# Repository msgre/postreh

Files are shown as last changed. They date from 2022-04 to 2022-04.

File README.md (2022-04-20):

Postřehová hra pro 2-4 hráče, realizovaná pro [Vrtuli, svět her a
poznání](https://zlatesipy.tomici.cz/vrtule/).

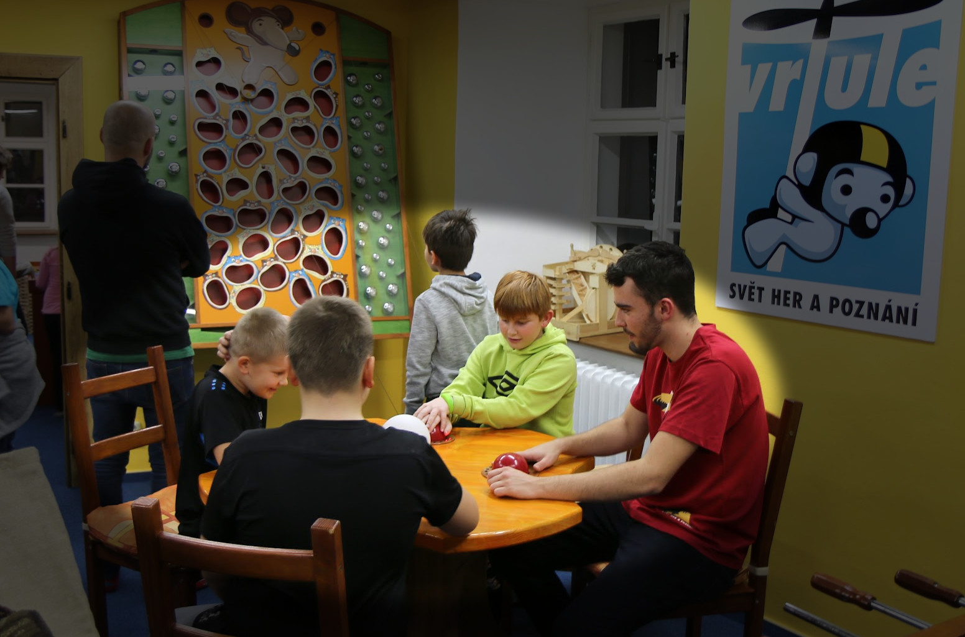
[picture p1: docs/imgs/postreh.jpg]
Hra Postřeh Hra postřeh


Jde o stolek se 4 tlačítky a světlem uprostřed.

Cílem hry je co nejdříve získat devět bodů. Ty se získávají stiskem tlačítka
ihned po rozsvícení světla uprostřed. Pokud se některý hráč unáhlí a stiskne
tlačítko ještě před rozsvícením, o bod přichází.

[Demonstrační video](https://youtu.be/h4fl8f8gwDo).

### Obsah

* [Hardware](#hardware)
* [Software](#software)
* [3D modely](#3d-modely)
* [Polepy](#polepy)
* [Opravy](#opravy)

## Hardware

Hru ovládá malý jednodeskový počítač Raspberry Pico (`U1`) a Micropython kód z
tohoto repozitáře. Hlavní světlo a signalizace získaných bodů jsou zrealizovány s
pomocí programovatelných diod Neopixel. Protože RPico používá 3.3V logiku, je
nutné mezi LED pásek a počítač vložit převodník logických úrovní (`U2`).
Tlačítka ze stolu (`SW1..4`) připínají 5V přímo na piny RPico. Na napájecích
pinech počítače a u konektorů vedoucích do Neopixelů jsou [dle
doporučení](https://learn.adafruit.com/adafruit-neopixel-uberguide/best-practices)
připojeny odrušovací kondenzátory (`C1..3`).

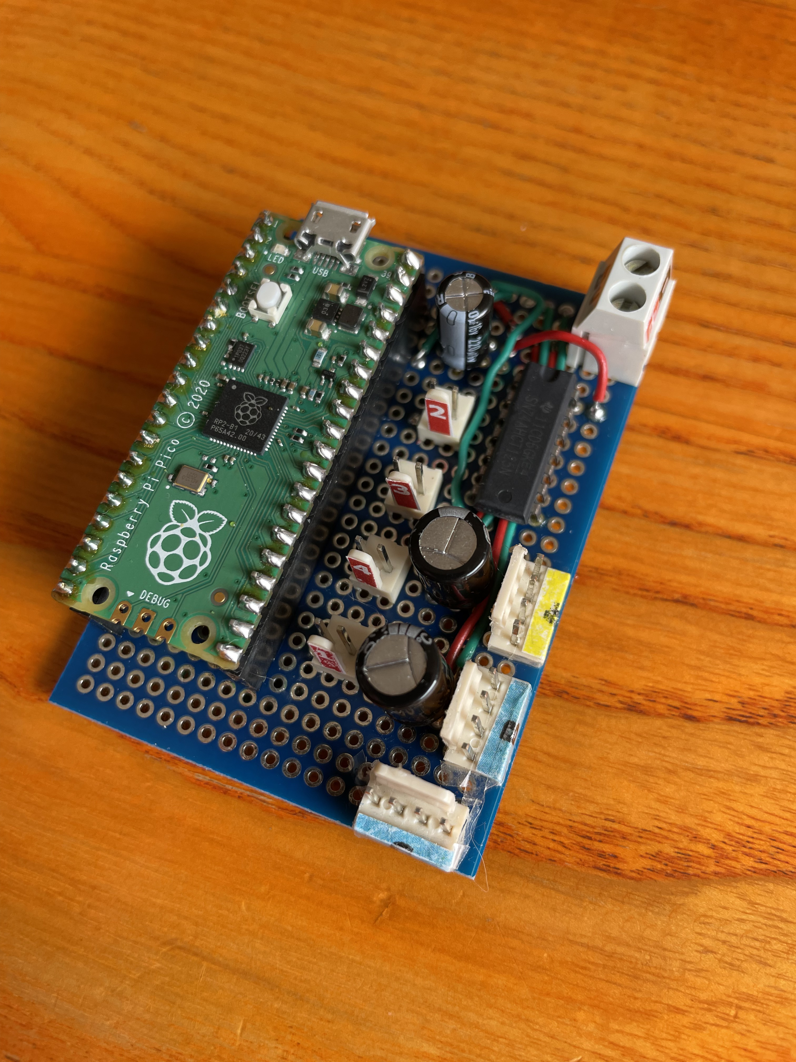
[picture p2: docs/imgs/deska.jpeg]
Ovládací deska


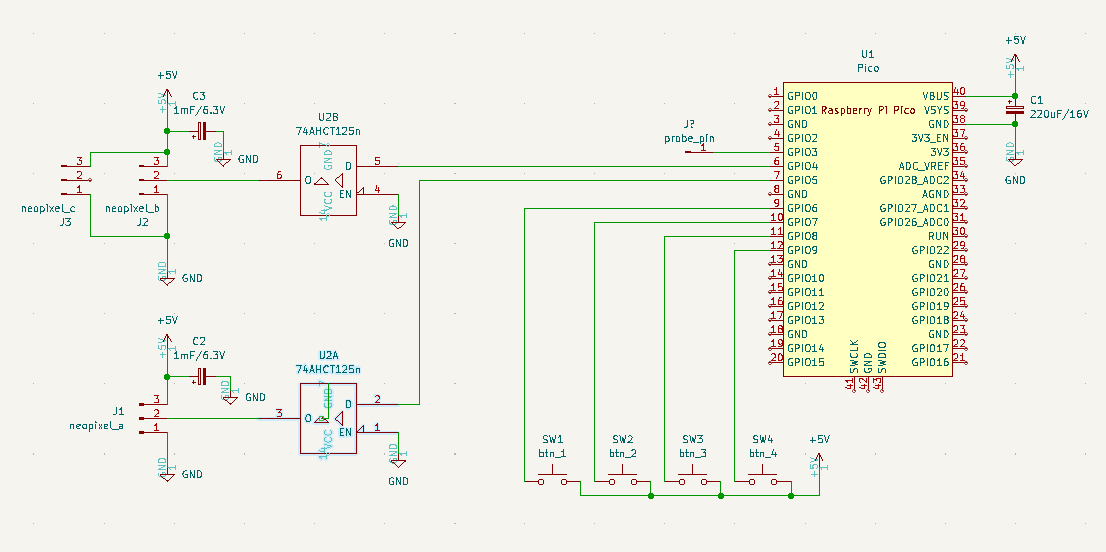
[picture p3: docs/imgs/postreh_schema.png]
Schéma zapojení


Do hlavního světla vedou 2 kablíky (`B` a `C`). Kabel `C` ale přivádí pouze
napájení doprostřed pásku, to aby diody v druhé polovině v důsledku úbytku
napětí nesvítily méně než ty v první polovině.

Upozornění: na datovém vstupu Neopixelů je připájen odpor 390R, který chrání
první diodu v pásku (ve schématu výše není zakreslen).

[Schéma zapojení v KiCadu](/schema/)

**Napájení**

Celou hru napájí malý spínaný 50W zdroj, připojený do svorek +/- na okraji desky.

Během vývoje jsem ale desku připojoval (a napájel) z externího docku co mám
u počítače, zkrz standardní RPico USB vstup. Pro klid duše je asi vhodné v této
konfiguraci stáhnout jas diod (konstanty `LED_MAIN_BRIGHTNESS` a `LED_NUMBERS_BRIGHTNESS`
v souboru `postreh/config.py`), ať proudy tekoucí z docku nejsou moc velké.

Hru utáhne i Powerbanka, opět připojená standardně přes RPico USB vstup
(odzkoušeno).

## Software

Hra je naprogramovaná pro Micropython v1.17 (Python 3.4).

Nahrávání SW dovnitř RPico je možné provést s pomocí aplikace
[Thonny](https://thonny.org/). Stačí nakopírovat soubor [`main.py`](/main.py) a kompletní
podadresář [`postreh/`](/postreh/).

Logika aplikace není nijak složitá. Snažil jsem se rozdělit funkční celky do
samostaných modulů. Hra se řídí stavovou mašinou dle následujícího nákresu:

Stavy

Jednotlivé stavy jsou popsány soubory v [`postreh/states/`](/postreh/states/).

V adresáři [`postreh/effects/`](postreh/effects/) jsou naimplementovaný vizuální efekty pro
Neopixel LEDky. Protože jejich tunění zabralo hodně času, jsou v
[`postreh/effects/tests/`](postreh/effects/tests/) jednoduché skripty, které po spuštěním v aplikaci
Thonny efekt oddemonstrují.

## 3D modely

V adresáři [`3d/`](/3d/) jsou uložené zdrojové 3D modely (Fusion 360) pro díly použité
v Postřehu a z nich vygenerované `.gcode` pro patřičné materiály a tiskárnu Prusa MK3.

[**Signalizace skóre**](/3d/postreh_cisla_u_tlacitek_v10.f3d)

Kulatý díl s prosvětlenými čísly. Skládá se z několika částí.

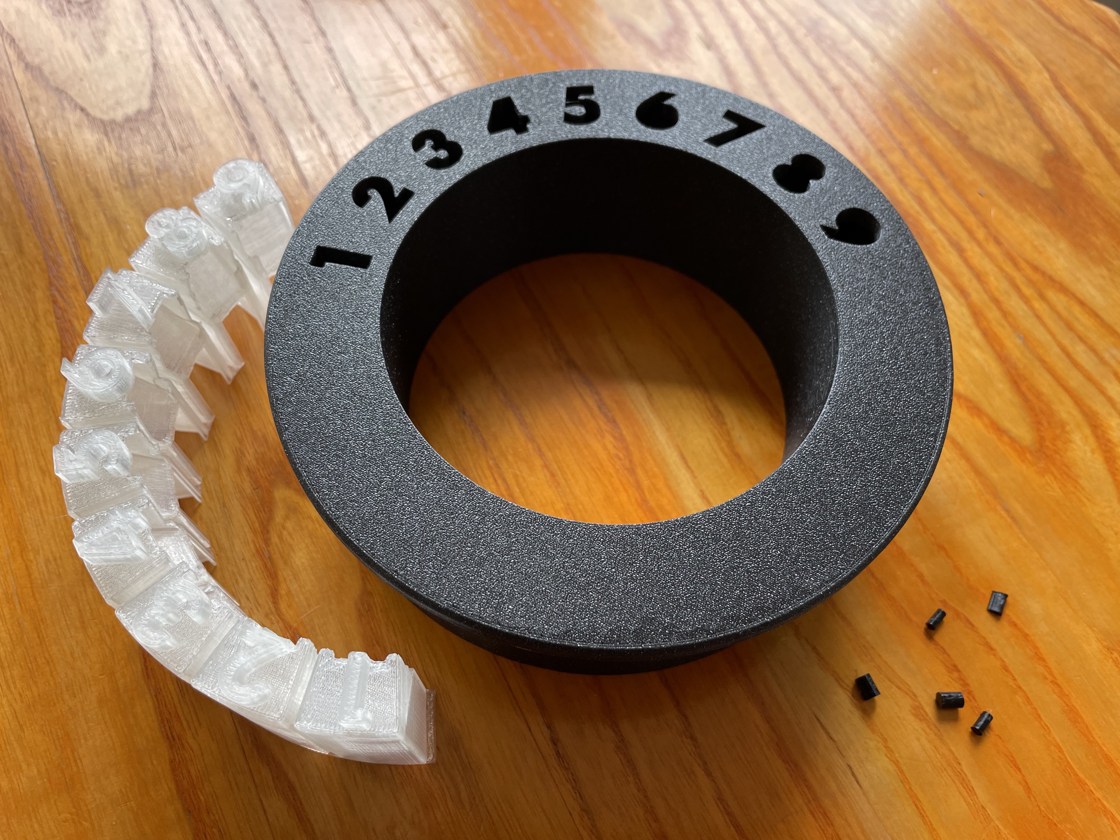
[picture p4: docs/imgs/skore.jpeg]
Signalizace skóre Signalizace skóre, starší verze


Hlavní díl (černý Prusament PETG) do kterého jsou vloženy Neopixely:

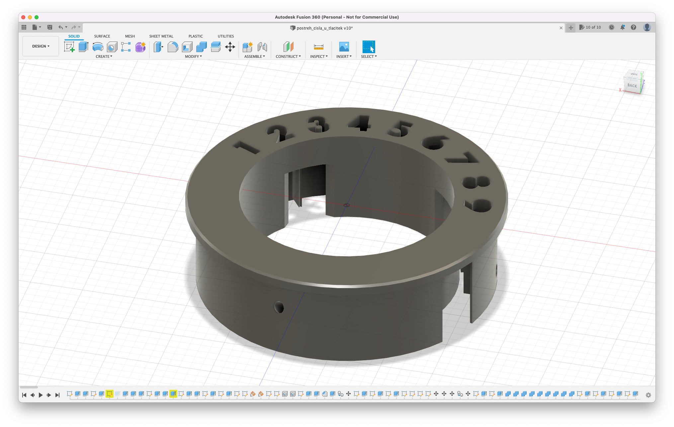
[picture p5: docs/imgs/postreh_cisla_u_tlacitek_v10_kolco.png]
Hlavní černý díl


Průsvitný díl s čísly (průsvitné noname PLA), který se vkládá do černého.
Jeho součástí jsou i šikmé plošky s nalepenou zrcadlovou fólií, která odráží
světlo z Neopixelů do čísel. Zároveň se stará o zafixování pozice Neopixel
pásku:

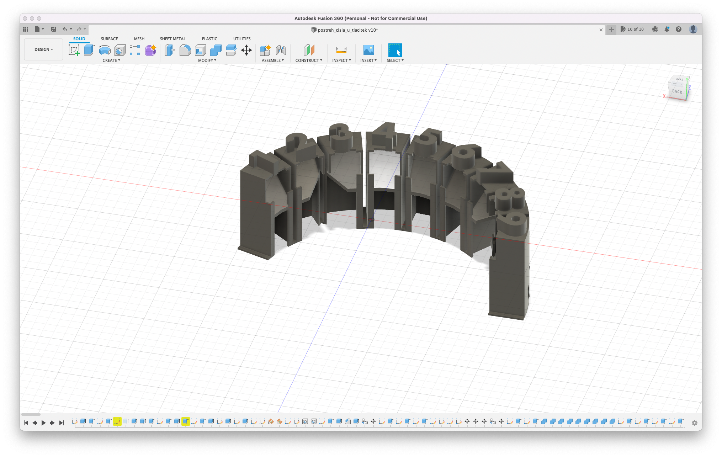
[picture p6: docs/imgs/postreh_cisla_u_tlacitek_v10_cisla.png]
Průsvitný díl s čísly


Titěrné středy čísel (černý Prusament PETG), které se vlepí dovnitř děr
v průhledném dílu:

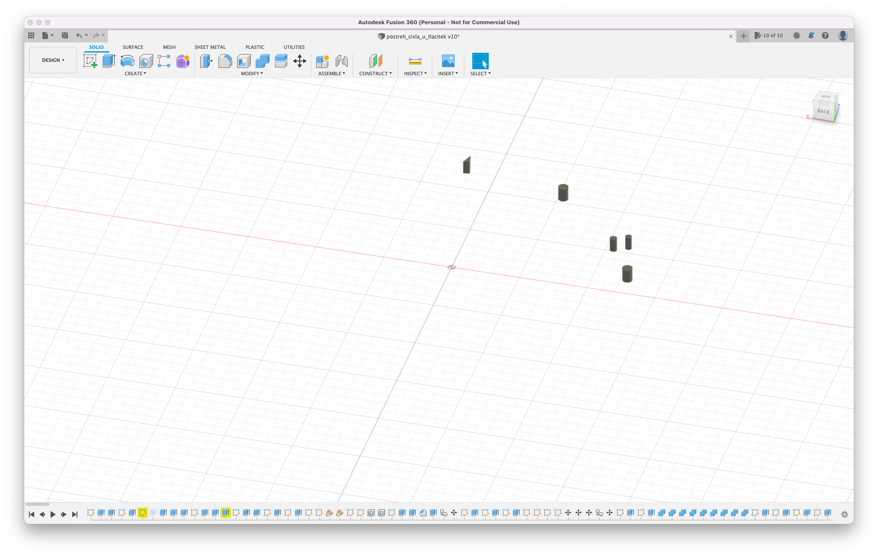
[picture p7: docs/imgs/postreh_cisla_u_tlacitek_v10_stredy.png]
Středy čísel


[**Žárovka**](/3d/postreh_zarovka_v3.f3d)

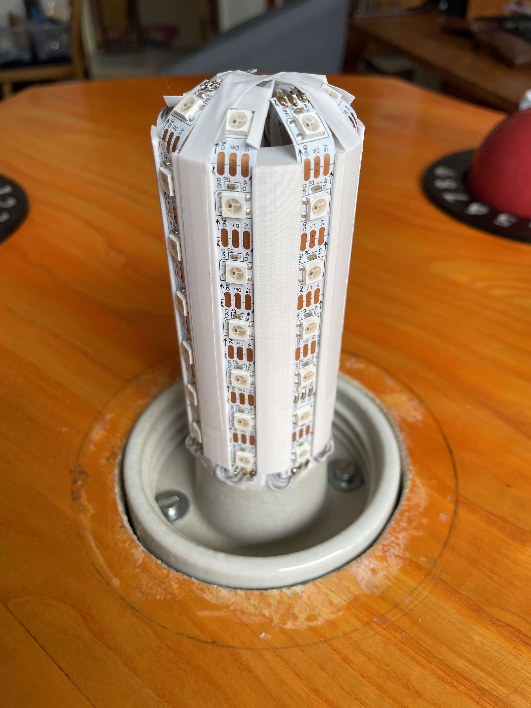
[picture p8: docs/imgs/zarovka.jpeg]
Zkompletovaná žárovka


Hlavní světlo je opět Neopixel pásek, ale zapojený tak, aby byl použitelný
jako žárovka (jde o sadu osmi pásků po 7-mi diodách zapojených za sebou):

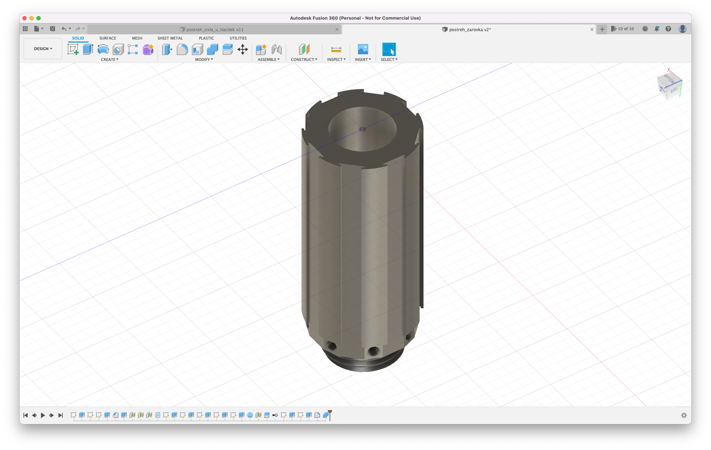
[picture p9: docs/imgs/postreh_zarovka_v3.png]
Žárovka


Volitelnou součástí je i díl, který zaoblí horní část žárovky. Neopixel pásky
pak nejsou na horní hraně tak namáhány (v aktuální verzi Postřehu jsme jej ale
nepoužili, diody byly už příliš blízko stínítka a nevypadalo to dobře):

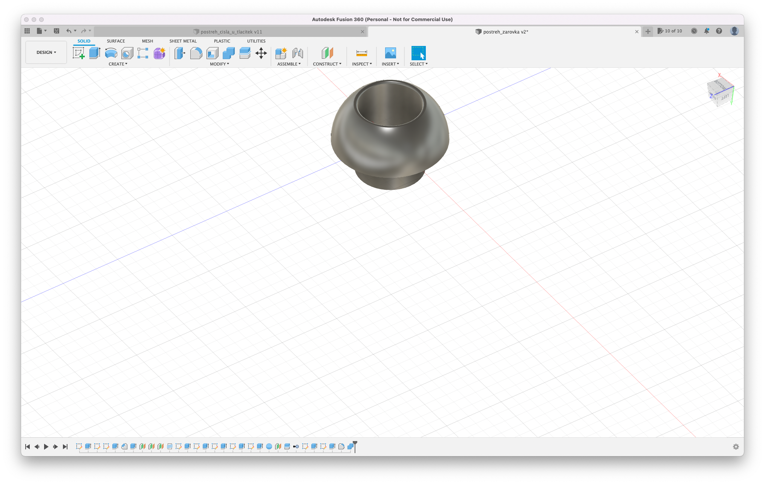
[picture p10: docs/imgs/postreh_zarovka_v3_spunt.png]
Špunt


[**Krytka stínítka**](/3d/krouzek_svetlo_v1.f3d)

Překrytí keramického dílu a nevzhledného středu na hrací desce:

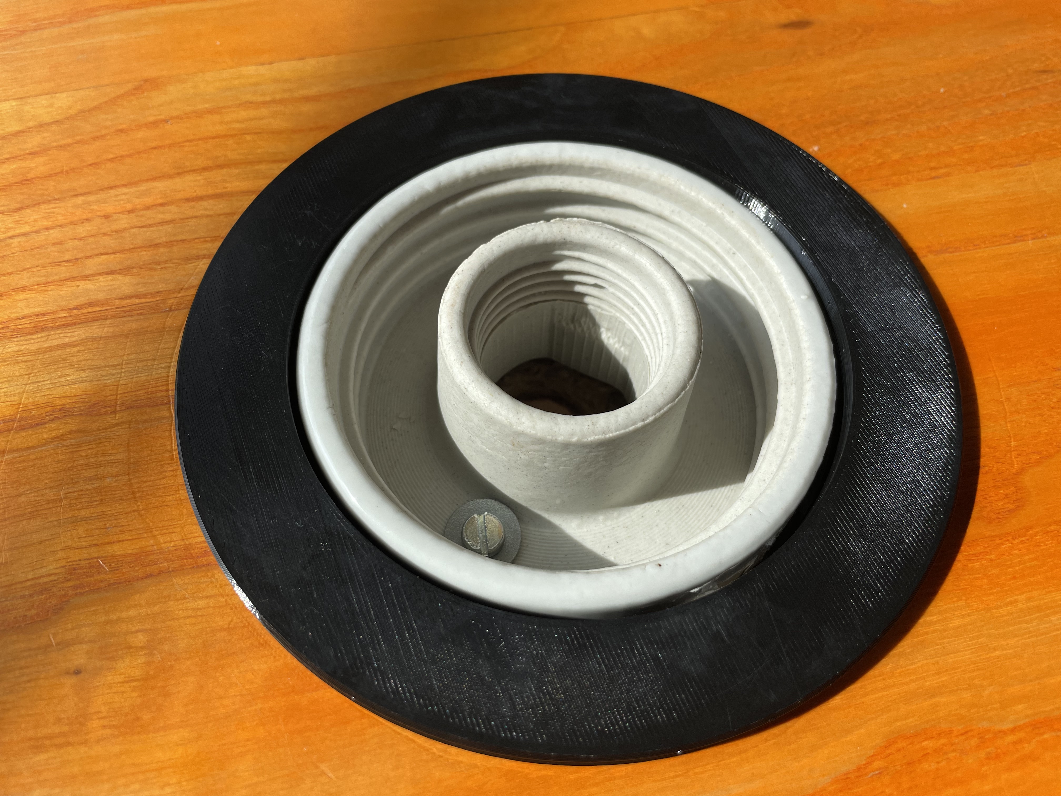
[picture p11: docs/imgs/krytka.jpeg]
Krytka


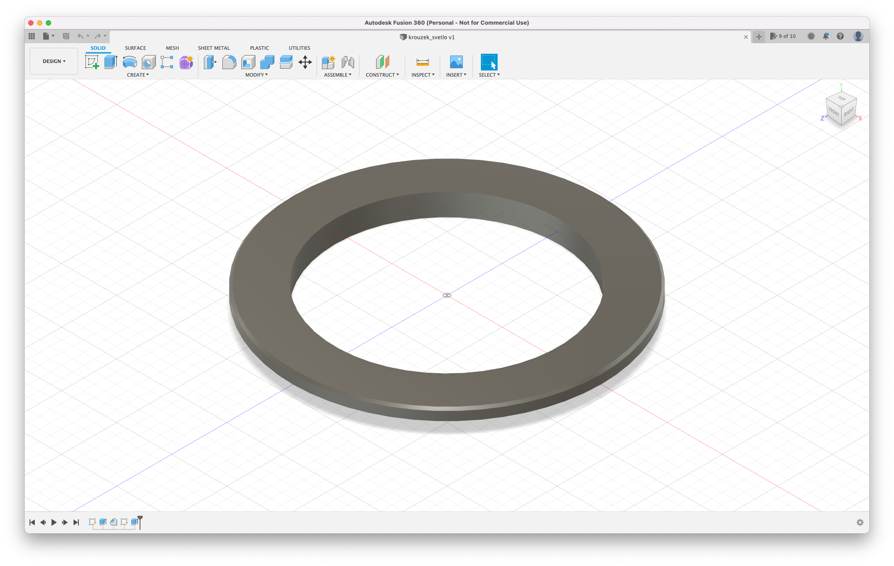
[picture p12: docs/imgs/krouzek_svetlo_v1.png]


[**Držák řídící desky**](/3d/drzak_ridici_desky_v1.f3d)

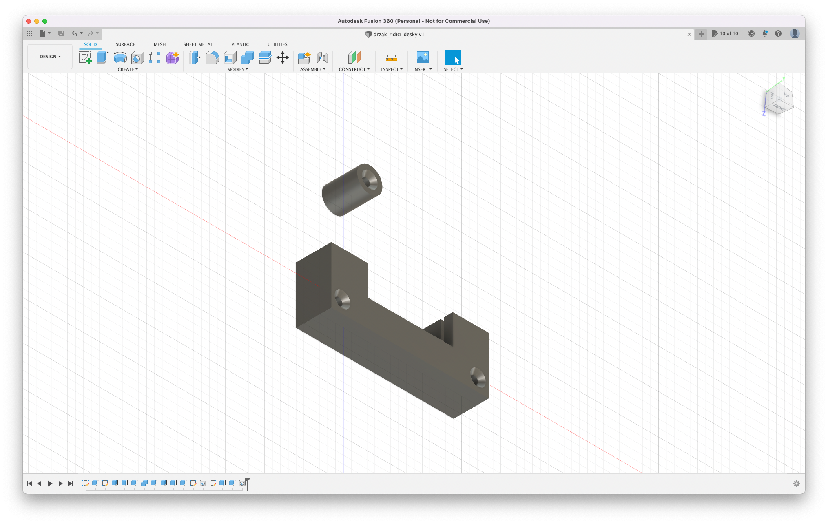
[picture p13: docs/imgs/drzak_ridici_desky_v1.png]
Držák řídící desky


## Polepy

Pro lepší přehlednost jsou konektory označené [barevnýma samolepkama](/docs/polepy.pdf) ([zdrojové SVG](/docs/polepy.svg))
a pod krytem je i [schématický návod](/docs/konektory.pdf) jak je zapojit ([zdrojové SVG](/docs/konektory.svg)).

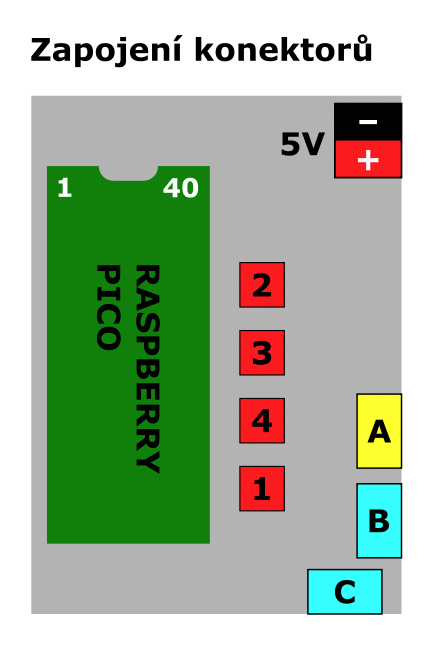
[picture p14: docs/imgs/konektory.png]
Konektory


## Opravy

Před jakoukoliv servisní manipulací odpoj Postřeh od elektřiny: sundej kryt na
stojanu a přepni vypínač do polohy 0.

### Jak sundat skleněné stínítko

1. **Odpoj elektřinu**
2. Polož ruku na stínítko, lehce zatlač a začni otáčet proti směru hodinových
   ručiček. Až se stínítko uvolní, pokračuj v otáčení a zároveň jej opatrně
   zvedej.

### Jak vyměnit/vytáhnout žárovku

1. **Odpoj elektřinu**
2. Odmontuj kryt na stojanu a odpoj modré konektory **B** a **C**
3. [Sundej skleněné stínítko](#jak-sundat-skleněné-stínítko)
4. Opatrně uchop žárovku a vyšroubuj ji proti směru hodinových ručiček. Po
   vyšroubování ji **pomalu** začni zvedat a dávej pozor ať se někde nezaseknou
   konektory.

### Jak vyměnit vadné tlačítko

1. **Odpoj elektřinu**
2. [Sundej skleněné stínítko](#jak-sundat-skleněné-stínítko)
3. [Odpoj a vytáhni žárovku](#jak-vyměnitvytáhnout-žárovku)
4. Odpoj tlačítka (červené konektory **1**, **2**, **3** a **4**)
5. Odpoj ovládání skóre (žlutý konektor **A**)
6. Odmontuj keramický držák skleněného stínítka (dva šrouby)
7. Poznamenej si orientaci hrací desky (až budeš hru zase skládat, musí být
   deska položená naprosto stejně, tlačítka a diody s číslama jsou spárované)
8. Odstraň XXX označené šrouby ze spodní strany a ve **dvou lidech** opatrně
   hrací desku nadzvedni. Z díry uprostřed stolu se začnou vytahovat uvolněné
   dráty od tlačítek. Třetí člověk musí všechny kabely vytáhnout a teprve pak
   můžeš desku odložit stranou.
9. Nyní máš přístup ke všem tlačítkům. Uvolni čtyři šrouby u vadného tlačítka
   a vyšroubuj všechny do výšky mezery mezi plastovou krabicí a dřevěným
   mačkadlem. Chytni tlačítko za dřevo a opatrně jej nadzdvihni.

Uvnitř krabice najdeš 2 tlačítka, zelené a červené.

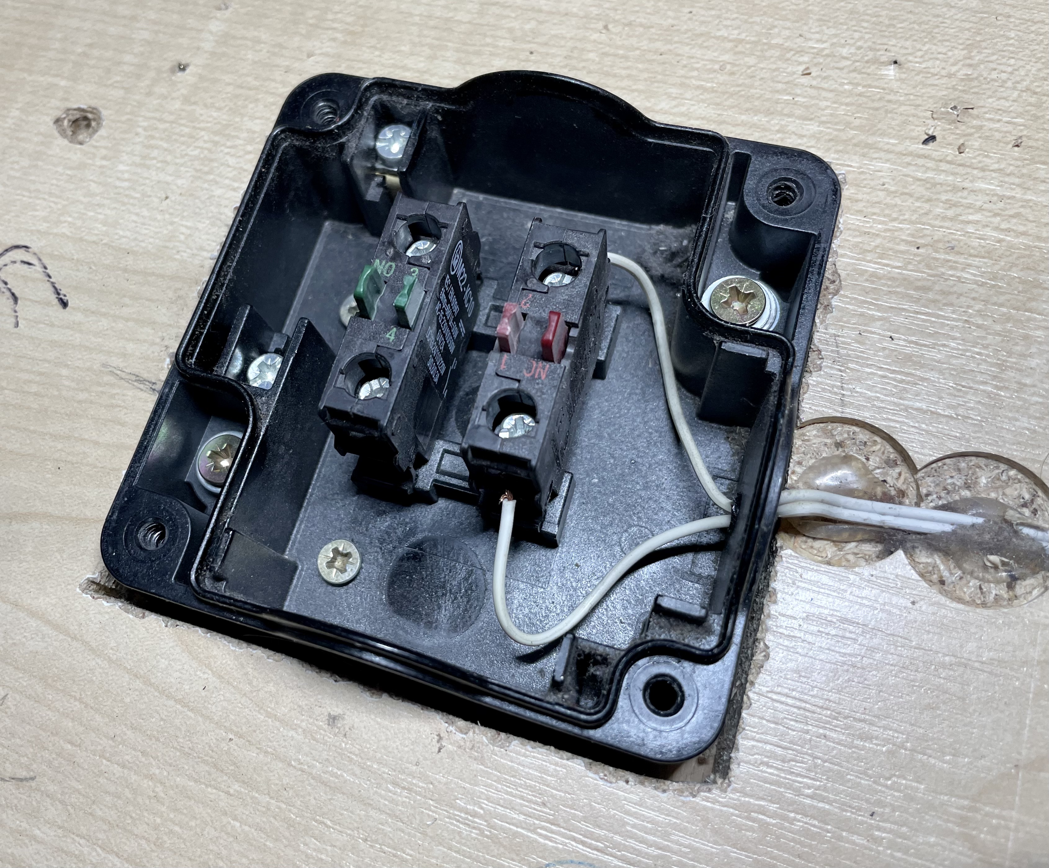
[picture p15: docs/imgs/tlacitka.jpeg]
Tlačítka v krabici


Zelené je NO (Normaly Open, zmáčknutím se sepne), červené je NC (Normaly
Closed, zmáčknutím se rozpojí). Obvykle využíváme zelené NC, ale pokud nějaké
tlačítko selže, nejprve se jej snažíme nahradit červeným a teprve pokud ani to
nefunguje, tak jej vyměníme fyzicky.

Podle toho které z tlačítek je využito je třeba adekvátně upravit konstantu
`BUTTON_CONFIG` v souboru [`postreh/config.py`](/postreh/config.py#L37-L43).

Upozornění: v krabici musí být vždy oba spínače, mechanismus tlačítka s tím
počítá. Nevyužitý spínač ale klidně může být vadný (proto je dobré je
nevyhazovat).

Upozornění: červené spínače (NC) jsou citlivější než zelené (NO)

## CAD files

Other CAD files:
3d/drzak_ridici_desky_v1.f3d
3d/krouzek_svetlo_v1.f3d
3d/postreh_zarovka_v3.f3d

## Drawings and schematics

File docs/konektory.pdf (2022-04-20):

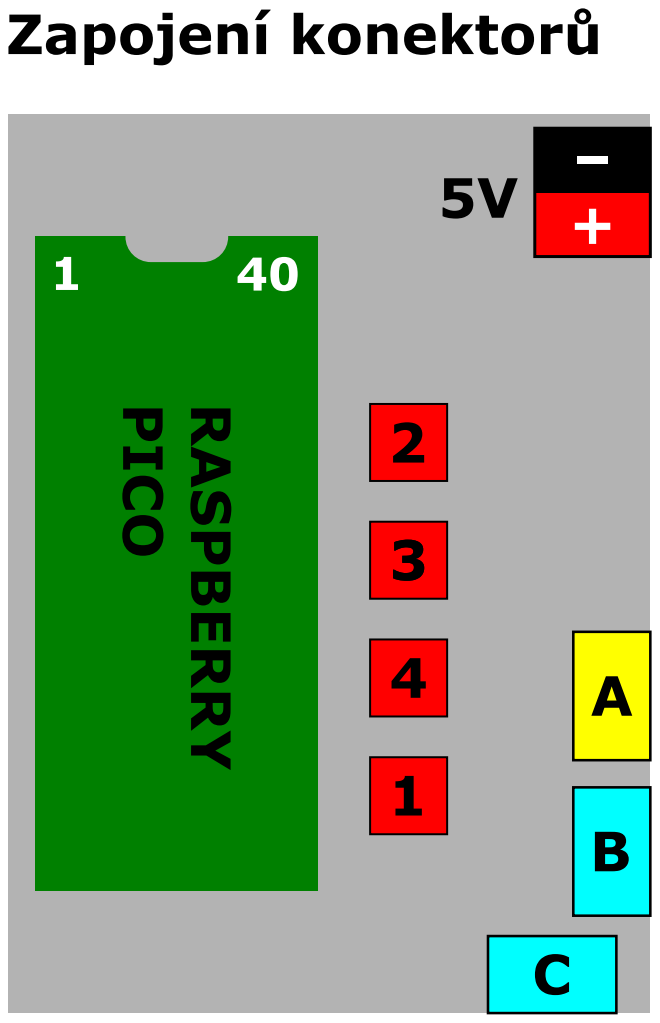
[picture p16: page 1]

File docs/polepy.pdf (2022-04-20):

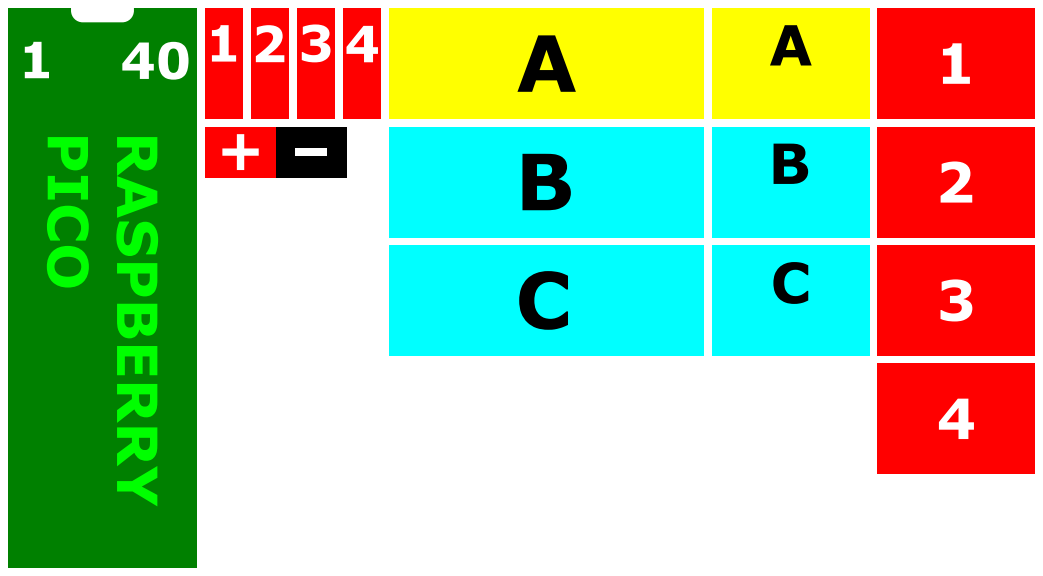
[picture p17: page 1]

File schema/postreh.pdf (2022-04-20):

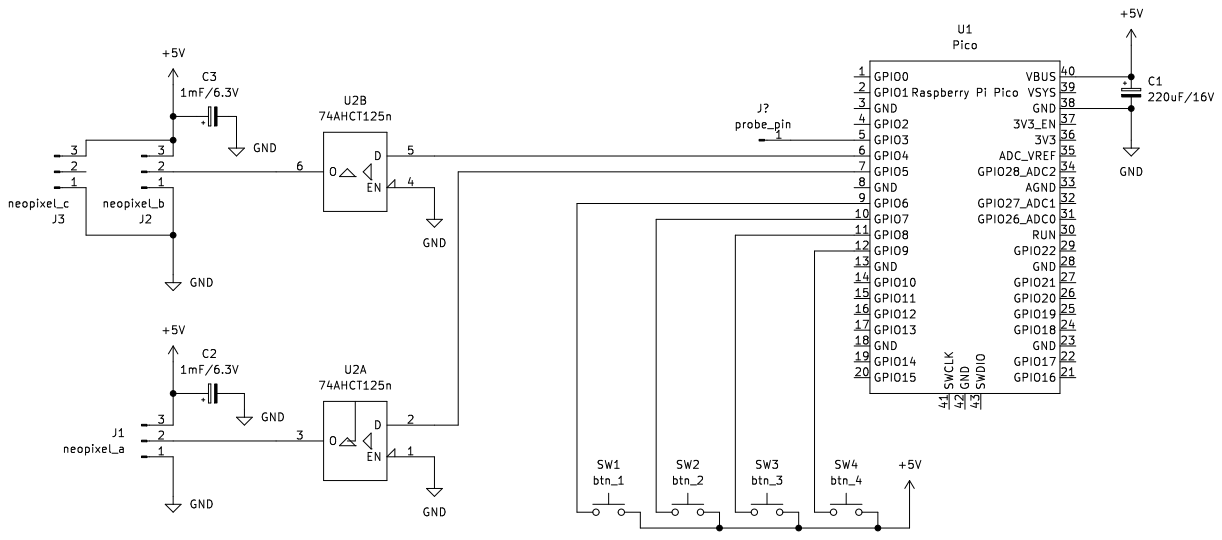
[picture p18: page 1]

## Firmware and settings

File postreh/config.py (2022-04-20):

"""
Globalni konfigurace hry.
"""

from postreh.colors import BLACK, WHITE, RED, GREEN, ORANGE

# obecne ----------------------------------------------------------------------

PLAYERS = 4
SCORES_PER_PLAYER = 9
MAIN_SLEEP = 1  # us


# konfigurace HW --------------------------------------------------------------

# tlacitka
PLAYER1_GPIO = 6
PLAYER2_GPIO = 7
PLAYER3_GPIO = 8
PLAYER4_GPIO = 9

# konfigurace NeoPixel prouzku v hlavnim svetle uprostred stolu
LED_MAIN_GPIO = 4
# majak je slozeny z LED_MAIN_COLUMNS prouzku, kde kazdy ma
# LED_MAIN_HEIGHT diod; jsou zapojene za sebe, takze se ovladaji
# pres jeden pin jako jeden souvisly pruh
LED_MAIN_COLUMNS = 8
LED_MAIN_HEIGHT = 7
LED_MAIN_COUNT = LED_MAIN_HEIGHT * LED_MAIN_COLUMNS
LED_MAIN_BRIGHTNESS = 1

# konfigurace NeoPixel prouzku zobrazujici skore hracu
LED_NUMBERS_GPIO = 5
LED_NUMBERS_COUNT = SCORES_PER_PLAYER * PLAYERS
LED_NUMBERS_BRIGHTNESS = 1

# konfigurace tlacitek hracu (podrobnosti viz postreh.hw.get_player_button)
BUTTON_CONFIG = {
    0: 1,
    1: 1,
    2: 0,
    3: 0,
}

# probe vystup (signal generovany na vystupnim pinu, v hlavni smycce)
# slouzi pro mereni realne doby jednoho ticku v ruznych stavech krz osciloskop
PROBE_ENABLED = False
PROBE_GPIO = 3


# stavy -----------------------------------------------------------------------

# NEW_ROUND
# jeden cyklus ve stavu KEYS trva 10.24ms
NEW_ROUND_RANDOM_MIN = 1  # ~1 vterina
NEW_ROUND_RANDOM_MAX = 30  # ~30 vterin
NEW_ROUND_RANDOM_BASE = 100

# WIN
# parametry efektu zmeny barvy hlavniho svetla na zelene
WIN_MAIN_PERIOD = 26
WIN_MAIN_COLOR1 = ORANGE
WIN_MAIN_COLOR2 = GREEN
WIN_MAIN_CYCLES = 1

# parametry efektu pri zablikani noveho skore u nejrychlejsiho hrace
WIN_NUMBER_PERIOD = 10
WIN_NUMBER_COLOR1 = BLACK
WIN_NUMBER_COLOR2 = WHITE
WIN_NUMBER_CYCLES = 15

# cekacka po zezelenani hlavniho svetla
WIN_WAIT_SLEEP = 10
WIN_WAIT_SLEEP_LIMIT = 60

# FAIL
# parametry efektu zmeny barvy hlavniho svetla na cervene
FAIL_MAIN_PERIOD = 26
FAIL_MAIN_COLOR1 = RED
FAIL_MAIN_CYCLES = 1

# parametry efektu pri zablikani ztraceneho skore u loosera
FAIL_NUMBER_PERIOD = 10
FAIL_NUMBER_COLOR1 = WHITE
FAIL_NUMBER_COLOR2 = BLACK
FAIL_NUMBER_CYCLES = 15

# cekacka po zcervenani hlavniho svetla
FAIL_WAIT_SLEEP = 10
FAIL_WAIT_SLEEP_LIMIT = 60

# SUNSET
# parametry efektu pri zhasinani hlavniho svetla
SUNSET_MAIN_PERIOD = 1000
SUNSET_MAIN_COLOR1 = ORANGE
SUNSET_MAIN_CYCLES = 1

# parametry efektu pri zhasinani cisel skore
SUNSET_NUMBERS_PERIOD = 2
SUNSET_NUMBERS_CYCLES = 500

# cekacka po zhasnuti
SUNSET_WAIT_SLEEP = 10
SUNSET_WAIT_SLEEP_LIMIT = 60

# KEYS
KEYS_SUNSET_TIMEOUT = 1200
KEYS_SLEEP = 10


# INTRO
# parametry efektu kdyz je hra v idle modu; poblikavani svetlusek
INTRO_CALM_FIREFLY_PERIOD = 100
INTRO_CALM_FIREFLY_PER_PERIOD = 2

# parametry efektu nekdo zmackne tlacitko; probuzeni vsech svetlusek
INTRO_ANGRY_FIREFLY_PERIOD = 4
INTRO_ANGRY_FIREFLY_PER_PERIOD = 1

# cekacka po probuzeni svetlusek
INTRO_WAIT_SLEEP = 10
INTRO_WAIT_SLEEP_LIMIT = 60

# parametry efektu odpoctu cisel skore
INTRO_COUNTDOWN_PERIOD = 20
INTRO_COUNTDOWN_COLOR = WHITE
INTRO_COUNTDOWN_WAIT = 40

# parametry efektu majaku
INTRO_BEACON_PERIOD = 4
INTRO_BEACON_COLOR = ORANGE
INTRO_BEACON_CYCLES = 17
INTRO_BEACON_SECTORS = 1


# GAME_OVER
# parametry efektu plazma koule
GAME_OVER_PLASMA_PERIOD = 1
GAME_OVER_PLASMA_CYCLES = 10
GAME_OVER_PLASMA_FADEOUT = 10

# parametry efektu tmavnuti skore spoluhracu
GAME_OVER_FADEOUT_PERIOD = 2
GAME_OVER_FADEOUT_CYCLES = 160

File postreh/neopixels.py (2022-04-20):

"""
Ovladani NeoPixel prouzku.
"""

import array
import rp2

from machine import Pin


@rp2.asm_pio(
    sideset_init=rp2.PIO.OUT_LOW,
    out_shiftdir=rp2.PIO.SHIFT_LEFT,
    autopull=True,
    pull_thresh=24,
)
def ws2812():
    """
    PIO rutina pro ovladani Neopixelu (WS2812).
    Copy/paste z https://datasheets.raspberrypi.com/pico/raspberry-pi-pico-python-sdk.pdf,
    kapitola 3.9.2

    Poznamka: jedna PIO rutina muze byt pouzita ve vice StateMachines
    (napr. pro ovladani vice prouzku v jednom projektu).
    """
    T1 = 2
    T2 = 5
    T3 = 3
    wrap_target()
    label("bitloop")
    out(x, 1).side(0)[T3 - 1]
    jmp(not_x, "do_zero").side(1)[T1 - 1]
    jmp("bitloop").side(1)[T2 - 1]
    label("do_zero")
    nop().side(0)[T2 - 1]
    wrap()


class NeopixelStrip:
    """
    Pomocna trida ovladajici prouzek Neopixelu.

    Index LED diod se pocita od 0, barvy se zadavaji v RGB prostoru
    jako tuple (R, G, B).

    Pouziti:
        # prouzek 20ti diod ovladany pres GPIO5, stavova masina ID=0
        LED_NUMBERS = NeopixelStrip(5, 20, 0)

        # zhasni vsecky diody
        LED_NUMBERS.fill((0, 0, 0))

        # jedenactou diodu rozsvit cervene
        LED_NUMBERS.set(10, (255, 0, 0))

        # teprem ted se to ukaze
        LED_NUMBERS.show()

    """

    def __init__(self, gpio, count, sm_id, brightness=0.2):
        """
        Parametry:
            gpio
                GPIO cislo pinu, pres ktery se Neopixely budou ovladat
            count
                pocet diod v prouzku
            sm_id
                ID stavove masiny; BACHA! pokud se v projektu vyskytne vice prouzku,
                kazdy musi mit sve vlastni ID
            brightness
                jas diod
        """
        self.count = count
        self.brightness = brightness
        self.sm = rp2.StateMachine(
            sm_id, ws2812, freq=8_000_000, sideset_base=Pin(gpio)
        )
        self.sm.active(1)
        self.array = array.array("I", [0 for _ in range(count)])

    def set(self, i, color):
        """
        Nastavi pixel na pozici "i" na barvu "color".
        """
        self.array[i] = (color[1] << 16) + (color[0] << 8) + color[2]

    def get(self, i):
        """
        Vrati RGB barvu ktera je nastavena na pozici "i".
        """
        c1 = self.array[i] >> 16
        c0 = (self.array[i] >> 8) & 255
        c2 = self.array[i] & 255
        return (c0, c1, c2)

    def fill(self, color):
        """
        Nastavi cely prouzek na barvu "color".
        """
        val = (color[1] << 16) + (color[0] << 8) + color[2]
        for i in range(self.count):
            self.array[i] = val

    def show(self):
        """
        Posle obsah internniho bufferu do Neopixelu, tj. teprve po zavolani
        teto metody se prouzek skutecne rozsviti.
        """
        dimmer_ar = array.array("I", [0 for _ in range(self.count)])
        for i, c in enumerate(self.array):
            r = int(((c >> 8) & 0xFF) * self.brightness)
            g = int(((c >> 16) & 0xFF) * self.brightness)
            b = int((c & 0xFF) * self.brightness)
            dimmer_ar[i] = (g << 16) + (r << 8) + b
        self.sm.put(dimmer_ar, 8)

    def set_brightness(self, value):
        """
        Aktualizuje hodnotu jasu prouzku.
        """
        self.brightness = value

    def get_brightness(self):
        """
        Vrati aktualni hodnotu jasu prouzku.
        """
        return self.brightness
